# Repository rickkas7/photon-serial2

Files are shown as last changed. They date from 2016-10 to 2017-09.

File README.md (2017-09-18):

# Serial2 on the Particle Photon

Normally, the Particle Photon has one UART hardware serial port (Serial1) and the USB serial port (Serial). There is another hardware UART serial port (Serial2), but getting to it is a pain. I don't recommend using it. 

Serial2 shares the same pins as the RGB status LED. This means that you have to disable to status LED. This will make debugging a pain in the future. If your code is running, you can mirror the status LED on another LED. Unfortunately that doesn't work when your code is not running, which is really when you need the status LED. Plus, you need to do soldering and remove some SMD resistors from the Photon. 

Anyway, you have been warned. Here we go!

## Making bottom connections 

Here's the bottom of the Photon (USB connector on the right).

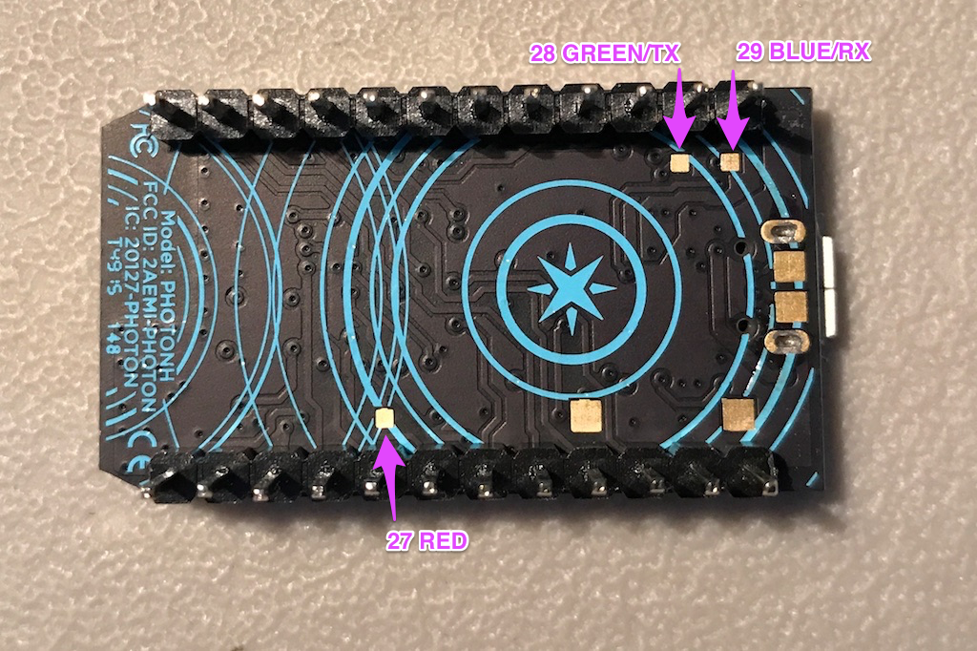
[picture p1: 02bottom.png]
Bottom Diagram


You need to make connections to pins 28 and 29 (the serial port) and optionally pin 27 (red LED). By doing all three, you can attach an external RGB LED to these pins, which may be helpful for debugging.

I used three female header sockets. You may prefer to use a different type of connector. Also, I decided that the pins should be mounted on the USB side, to keep the metal from the connectors out of the keep-away zone under the antenna.

Here is is after soldering the leads in place:

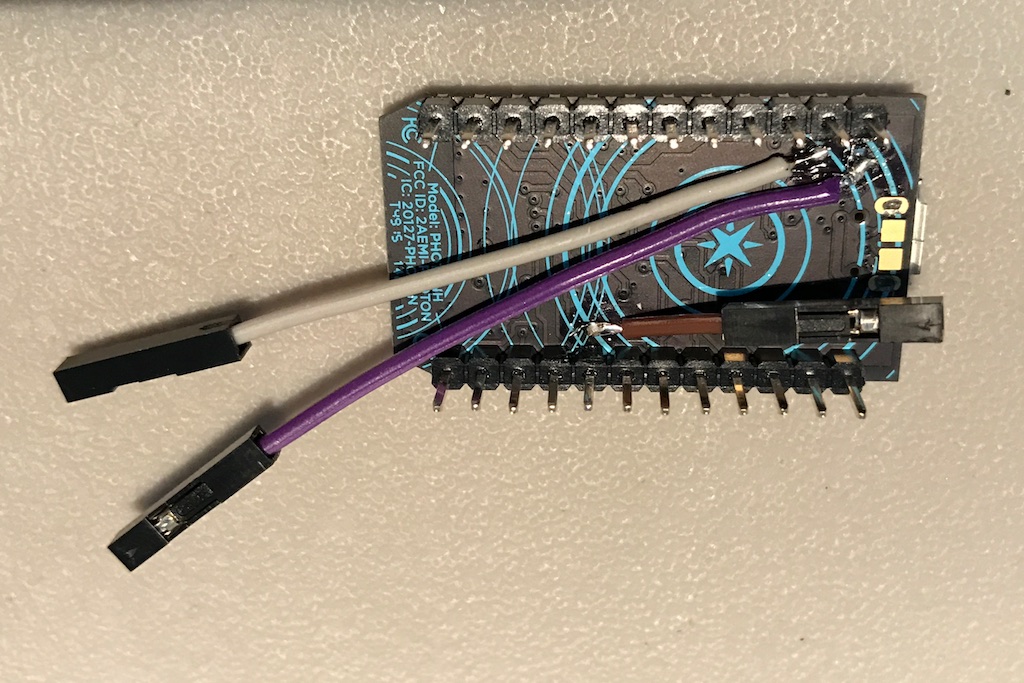
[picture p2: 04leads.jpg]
Leads soldered


- White Wire: 28 Green LED/TX
- Purple Wire: 29 Blue LED/RX
- Brown Wire: 27 Red LED

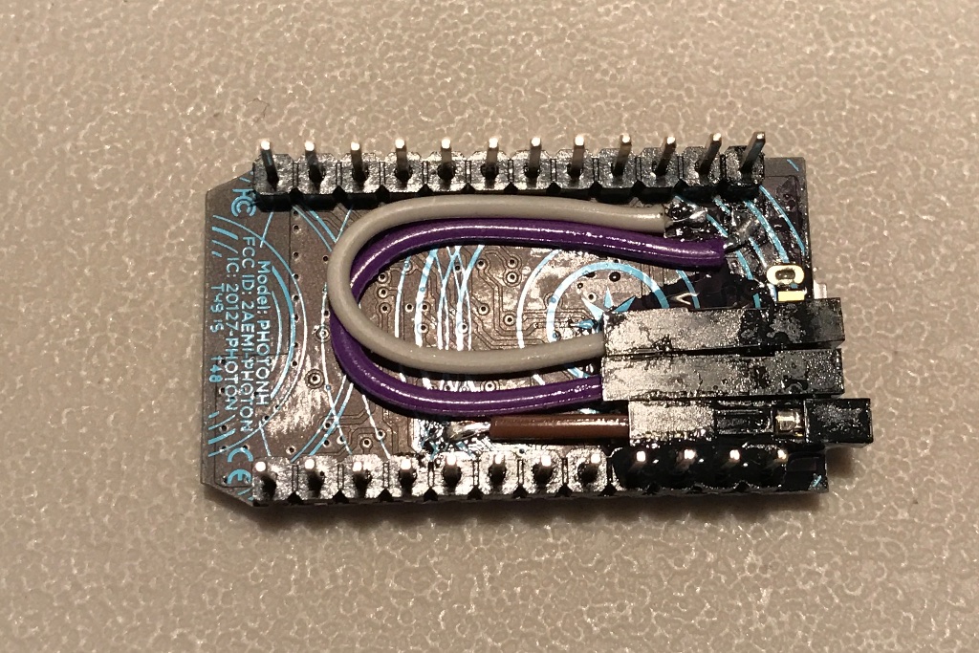
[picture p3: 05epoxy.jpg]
Epoxy in place


I used epoxy to glue the headers in place. This was more difficult and messier than I anticipated.

There is a much better way of doing this at the end of the document!

## Testing out the LED

One advantage of making all three connections is that you can verify your wiring by using an external common anode RGB LED. I used [this one from Adafruit](https://www.adafruit.com/products/159) but any common anode LED should work.

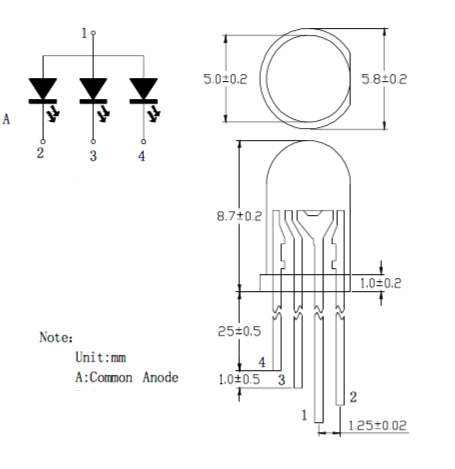
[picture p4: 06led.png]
LED


Left to right when positioned as shown above (flat side on right, longest lead is second from right):

- 4 = Blue
- 3 = Green
- 1 = Common Anode (longest lead)
- 2 = Red

Here is the external LED connected to the pins:

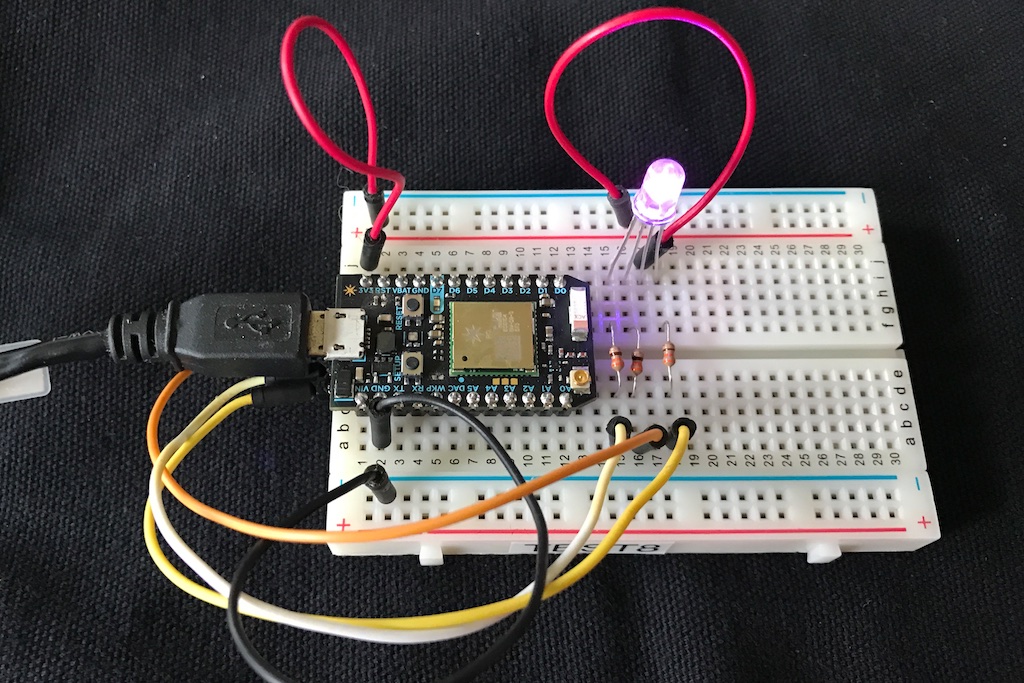
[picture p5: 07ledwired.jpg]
LED Wired


- Orange wire: Photon pin 28 to LED pin 4, blue
- White wire: Photon pin 29 to LED pin 3, green
- Yellow wire: Photon pin 27 to LED pin 2, red

There is also a 330 ohm resistor on each of the 3 cathodes.

With any luck, everything will be working properly, verifying the connections on the bottom are good and you didn't break anything.

## Disconnecting the built-in LED

Here's where things get more destructive. You need to disconnect the built-in RGB LED when using Serial2 because otherwise the TX and RX pins will be connected via the LED, and data corruption will likely result. The easiest and safest way to do this is to remove the 3 current limiting resistors R1, R2, and R7.

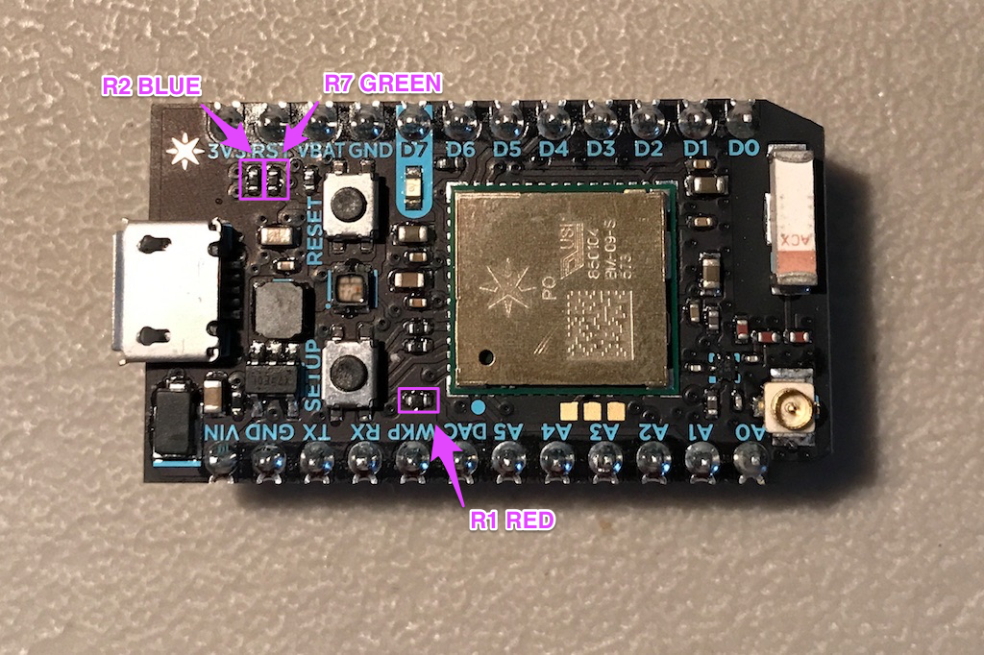
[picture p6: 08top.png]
Top Diagram


If you have an SMD hot air rework station, it would be easy to remove these resistors.

In theory you should be able to remove them with a soldering iron. I had trouble doing this, so I used a drill press with a 1/16" bit and the stop set to make sure I didn't drill into the circuit board. 

Here's the Photon with the resistors removed:

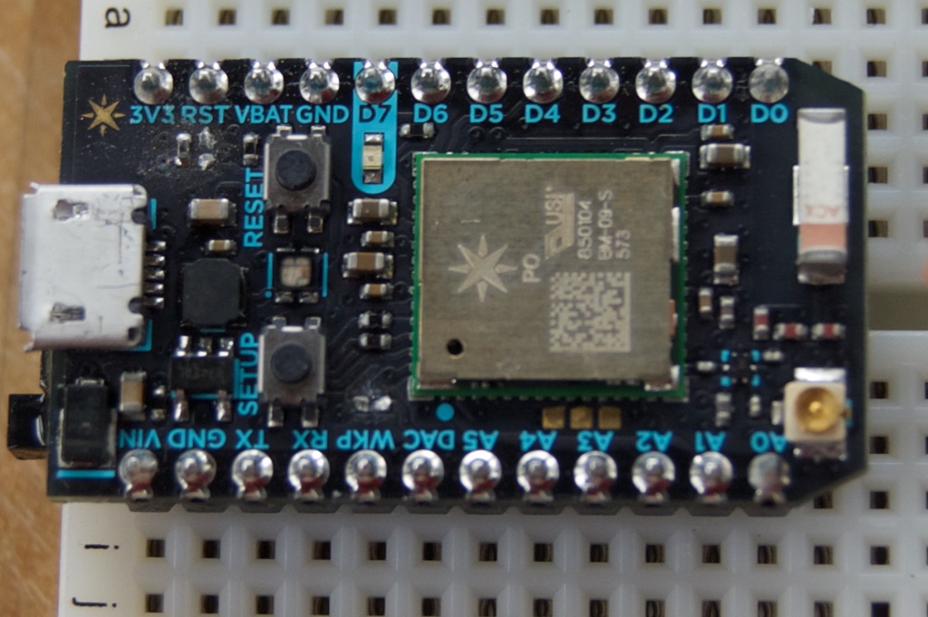
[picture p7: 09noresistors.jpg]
No resistors


It took a few tries, but you can tell you did it successfully when you boot up and the status LED doesn't light up. 

## Using the alternate status LED (0.6.1 and later)

This should set the alternate status LED to work automatically from the boot loader with 0.6.1 and later. 

```
STARTUP(RGB.mirrorTo(D2, D3, A4, true, true));

void setup() {
}

void loop() {
}
```

## Using the alternate status LED (0.6.0 and earlier)

To use the status LED on different pins, you must choose other pins that have PWM support. I selected:

- D2: Red LED (yellow wire)
- D3: Green (orange wire)
- A4: Blue (white wire)

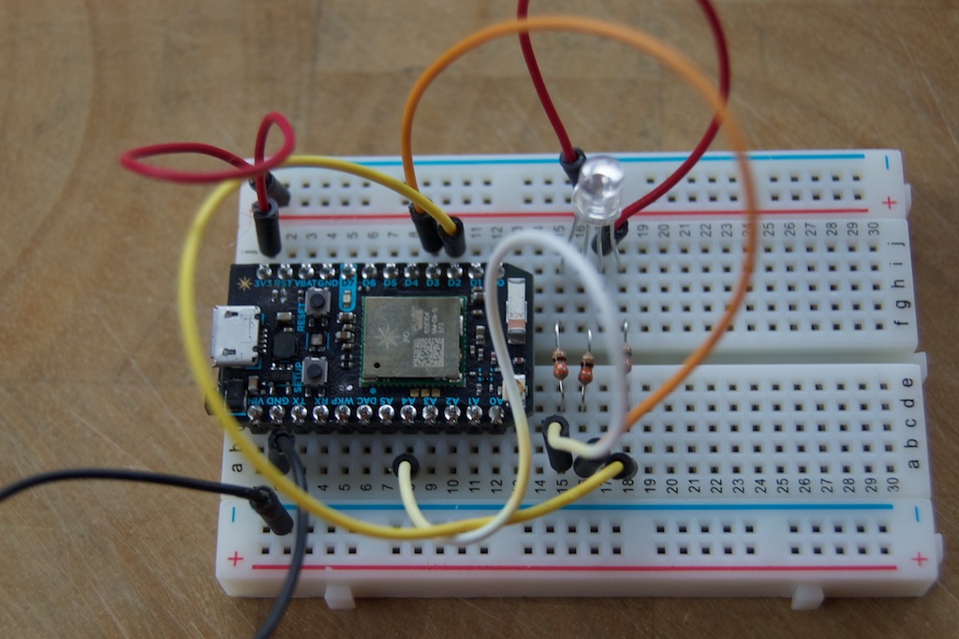
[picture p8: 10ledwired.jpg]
LED wired to alternate location


The documentations for [tone](https://docs.particle.io/reference/firmware/photon/#tone-) more details of which pins you can use. I purposely avoided D0/D1 since I2C can be handy, and TX/RX since why would to go through the insanity if you didn't need both UART serial ports.

And here's the sample code to test out the LED on the new pins:

```
#include "Particle.h"

SYSTEM_THREAD(ENABLED);

// These must be PWM compatible pins, all on different timers. See:
// https://docs.particle.io/reference/firmware/photon/#tone-
const int RED_PIN = D2;
const int GREEN_PIN = D3;
const int BLUE_PIN = A4;

// LED is a common anode RGB LED, like:
// https://www.adafruit.com/products/159
//
// (    LED   ]  <- flattened side
//  |  |  |  |
//  4  |  |  |
//     3  |  2
//        1
// Left to right:
// 4 = Blue
// 3 = Green
// 1 = Common Anode (longest lead)
// 2 = Red

// Forward declaration
void ledChangeHandler(uint8_t r, uint8_t g, uint8_t b);

void setup() {
	Serial.begin(9600);

	pinMode(RED_PIN, OUTPUT);
	pinMode(GREEN_PIN, OUTPUT);
	pinMode(BLUE_PIN, OUTPUT);
	RGB.onChange(ledChangeHandler);

}

void loop() {
}

void ledChangeHandler(uint8_t r, uint8_t g, uint8_t b) {
	analogWrite(RED_PIN, 255 - r);
	analogWrite(GREEN_PIN, 255 - g);
	analogWrite(BLUE_PIN, 255 - b);
}

```

## Using the serial port

Of course the whole reason to do this was to use the Serial2 port. 

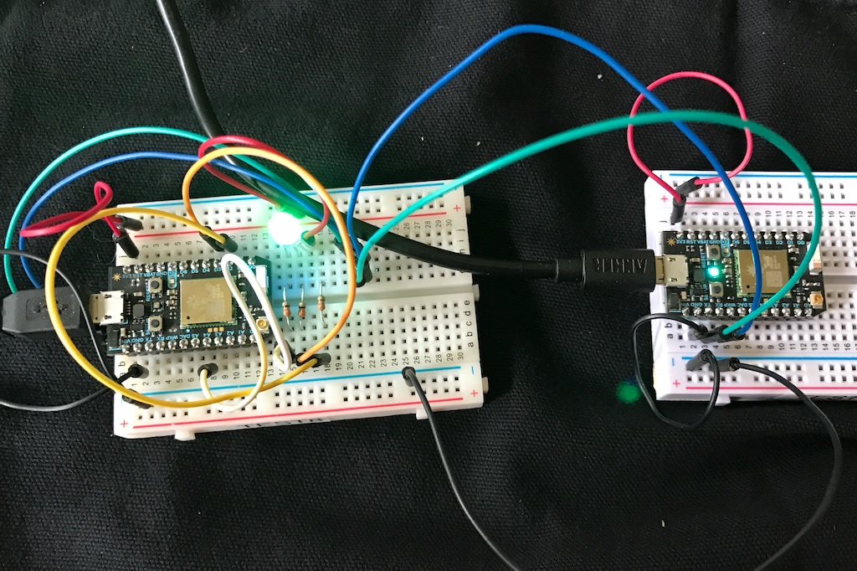
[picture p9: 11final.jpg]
Final test


When you're looking at the modified Photon from the USB port side for serial port use: 

- Serial2 TX (green wire)
- Serial2 RX (blue wire)
- no connection

Here's the code that I ran on the left (modified) Photon:

```
#include "Particle.h"

#include "Serial2/Serial2.h"

SYSTEM_THREAD(ENABLED);

// These must be PWM compatible pins, all on different timers. See:
// https://docs.particle.io/reference/firmware/photon/#tone-
const int RED_PIN = D2;
const int GREEN_PIN = D3;
const int BLUE_PIN = A4;
const size_t READ_BUF_SIZE = 64;

// Forward declaration
void ledChangeHandler(uint8_t r, uint8_t g, uint8_t b);
void processBuffer();

// Global variables
char readBuf[READ_BUF_SIZE];
size_t readBufOffset = 0;

void setup() {
	Serial.begin(9600);
	Serial2.begin(9600);

	pinMode(RED_PIN, OUTPUT);
	pinMode(GREEN_PIN, OUTPUT);
	pinMode(BLUE_PIN, OUTPUT);
	RGB.onChange(ledChangeHandler);
}

void loop() {
	// Read data from serial
	while(Serial2.available()) {
		if (readBufOffset < READ_BUF_SIZE) {
			char c = Serial2.read();
			if (c != '\n') {
				// Add character to buffer
				readBuf[readBufOffset++] = c;
			}
			else {
				// End of line character found, process line
				readBuf[readBufOffset] = 0;
				processBuffer();
				readBufOffset = 0;
			}
		}
		else {
			readBufOffset = 0;
		}
	}

}

void processBuffer() {
	int receivedValue = atoi(readBuf);

	// This program just increments the value sent by the Photon and returns it
	Serial2.printf("%d\n", receivedValue + 1);
}

void ledChangeHandler(uint8_t r, uint8_t g, uint8_t b) {
	// For a common anode LED, you need to use
	analogWrite(RED_PIN, 255 - r);
	analogWrite(GREEN_PIN, 255 - g);
	analogWrite(BLUE_PIN, 255 - b);
}
```

And the Photon Test2 on the right:

```
#include "Particle.h"

// Constants
const unsigned long SEND_INTERVAL_MS = 2000;
const size_t READ_BUF_SIZE = 64;

// Forward declarations
void processBuffer();

// Global variables
int counter = 0;
unsigned long lastSend = 0;

char readBuf[READ_BUF_SIZE];
size_t readBufOffset = 0;

void setup() {
	Serial.begin(9600);

	// Serial1 RX is connected to other Photon TX
	// Serial2 TX is connected to other Photon RX
	// Photon GND is connected to other Photon GND
	Serial1.begin(9600);
}

void loop() {
	if (millis() - lastSend >= SEND_INTERVAL_MS) {
		lastSend = millis();

		Serial1.printlnf("%d", ++counter);
		Serial.printlnf("Sent to other Photon: %d", counter);
	}

	// Read data from serial
	while(Serial1.available()) {
		if (readBufOffset < READ_BUF_SIZE) {
			char c = Serial1.read();
			if (c != '\n') {
				// Add character to buffer
				readBuf[readBufOffset++] = c;
			}
			else {
				// End of line character found, process line
				readBuf[readBufOffset] = 0;
				processBuffer();
				readBufOffset = 0;
			}
		}
		else {
			Serial.println("readBuf overflow, emptying buffer");
			readBufOffset = 0;
		}
	}

}

void processBuffer() {
	Serial.printlnf("Received from other Photon: %s", readBuf);
}
```

And the output from Test2:

```
particle serial monitor /dev/cu.usbmodemFD1141
Opening serial monitor for com port: "/dev/cu.usbmodemFD1141"
Sent to other Photon: 1
Received from other Photon: 2
Sent to other Photon: 2
Received from other Photon: 3
Sent to other Photon: 3
Received from other Photon: 4
Sent to other Photon: 4
Received from other Photon: 5
Sent to other Photon: 5
Received from other Photon: 6
```

## Better way of making bottom connections

There is a much better way of making the bottom connections, as well. Using the "no headers" version of the Photon, it can be surface mounted on a printed circuit board:

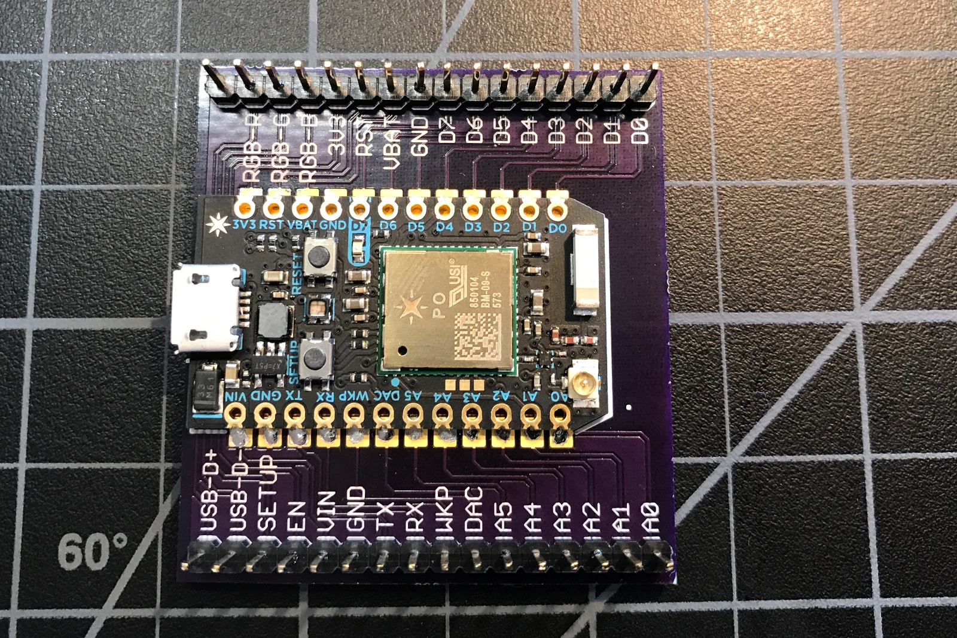
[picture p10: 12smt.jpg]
SMT Photon


This is just a test board that exposes all of the bottom connections as well as the standard Photon pins. This works best if you have a reflow oven to bake the Photon onto the circuit board, as it's impossible to hand-solder to the bottom pads in the SMT configuration.

The standard Eagle footprints for the SMT version of the Electron include the bottom pads. The schematic and board file for this board are included in the "eagle" directory.

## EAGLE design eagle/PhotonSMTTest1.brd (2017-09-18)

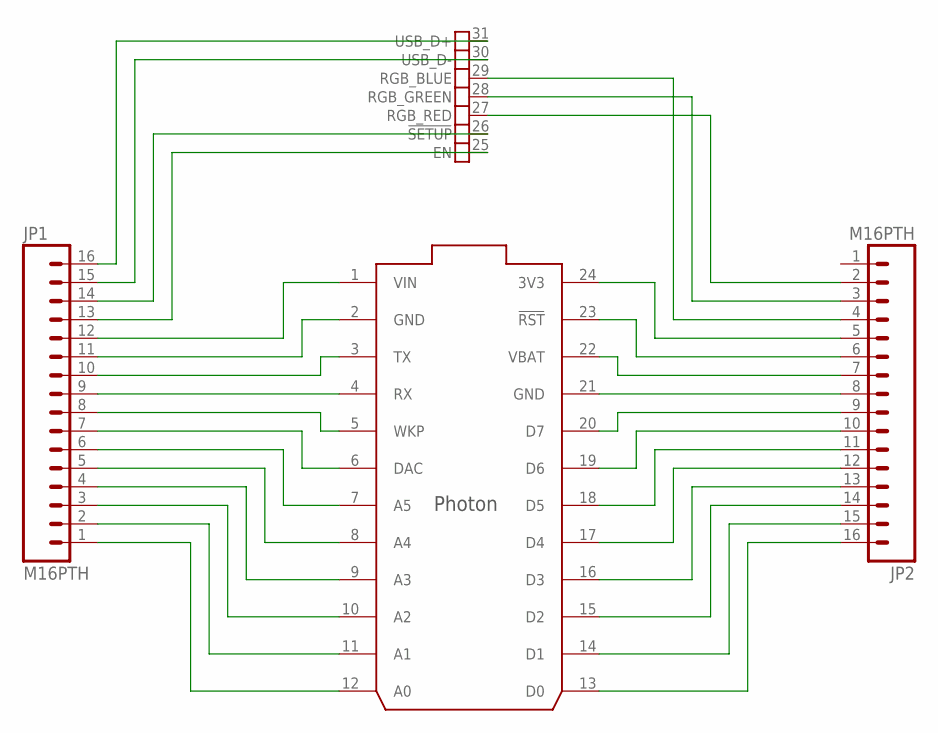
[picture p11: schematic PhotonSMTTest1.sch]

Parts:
.: PHOTON_SMD
JP1, JP2: M16PTH; 1X16

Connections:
GND: ..2 (GND), ..21 (GND), JP1.11, JP2.8
unnamed: ..1 (VIN), JP1.12
unnamed: ..31 (USB_D+), JP1.16
unnamed: ..3 (TX), JP1.10
unnamed: ..4 (RX), JP1.9
unnamed: ..6 (DAC), JP1.7
unnamed: ..8 (A4), JP1.5
unnamed: ..7 (A5), JP1.6
unnamed: ..5 (WKP), JP1.8
unnamed: ..9 (A3), JP1.4
unnamed: ..10 (A2), JP1.3
unnamed: ..11 (A1), JP1.2
unnamed: ..12 (A0), JP1.1
unnamed: ..24 (3V3), JP2.5
unnamed: ..23 (!RST), JP2.6
unnamed: ..22 (VBAT), JP2.7
unnamed: ..30 (USB_D-), JP1.15
unnamed: ..20 (D7), JP2.9
unnamed: ..19 (D6), JP2.10
unnamed: ..18 (D5), JP2.11
unnamed: ..17 (D4), JP2.12
unnamed: ..16 (D3), JP2.13
unnamed: ..15 (D2), JP2.14
unnamed: ..14 (D1), JP2.15
unnamed: ..13 (D0), JP2.16
unnamed: ..29 (RGB_BLUE), JP2.4
unnamed: ..28 (RGB_GREEN), JP2.3
unnamed: ..27 (RGB_RED), JP2.2
unnamed: ..26 (!SETUP), JP1.14
unnamed: ..25 (EN), JP1.13

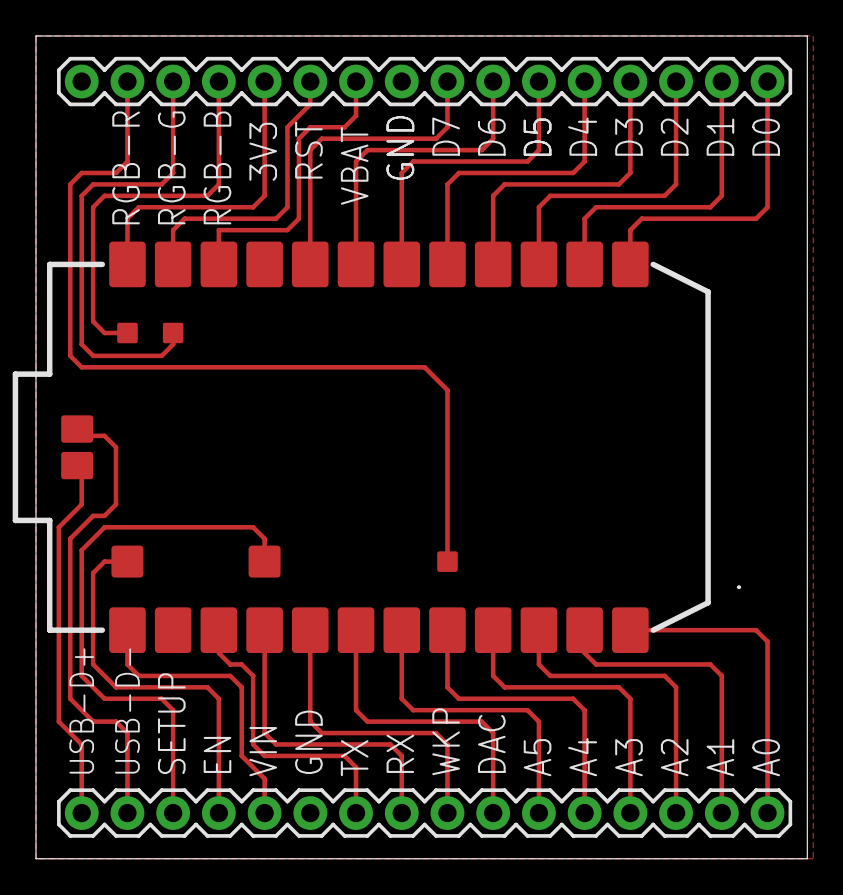
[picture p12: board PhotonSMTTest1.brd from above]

Board: 2 copper layers, 42.9 x 45.7 mm, 3 parts (0 on the bottom side), 30 nets.

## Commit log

2016-10-30 fix incorrect picture for alt led
2017-09-18 Add SMT instructions and files
    [PhotonSMTTest1.brd, PhotonSMTTest1.sch]

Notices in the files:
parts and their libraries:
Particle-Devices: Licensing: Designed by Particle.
